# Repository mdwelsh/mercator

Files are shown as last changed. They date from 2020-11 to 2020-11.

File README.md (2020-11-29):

# Mercator

Mercator is a spherical persistence-of-vision display based on ESP32 and
DotStar LEDs. This repo contains the full source files, laser cut and 3D
printed parts designs, and custom PCB design.

For more details, please check out the article here:
https://mdwdotla.medium.com/mercator-an-esp32-based-spherical-persistence-of-vision-display-a4beff4f826e

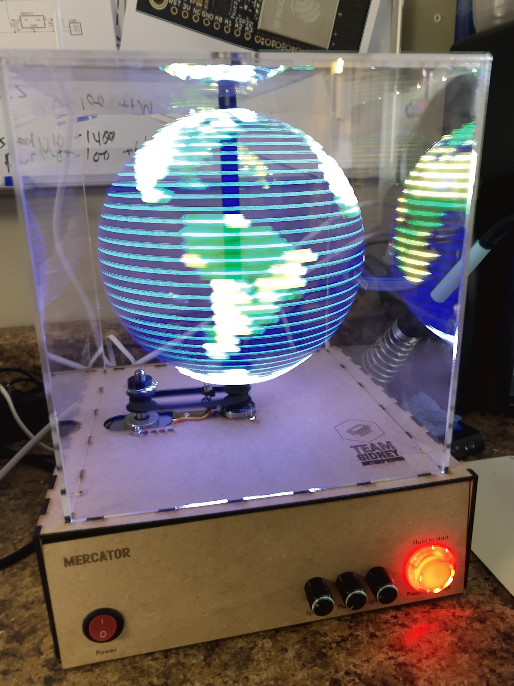
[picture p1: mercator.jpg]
Image of Mercator


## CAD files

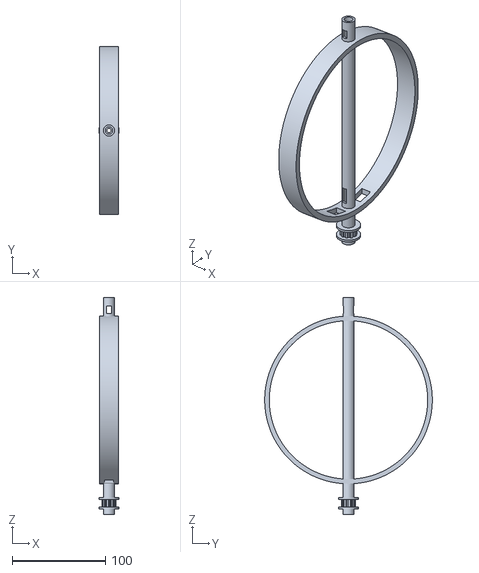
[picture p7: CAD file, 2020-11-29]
hardware/3dprint/Ring.stl
22.0 x 180.0 x 233.0

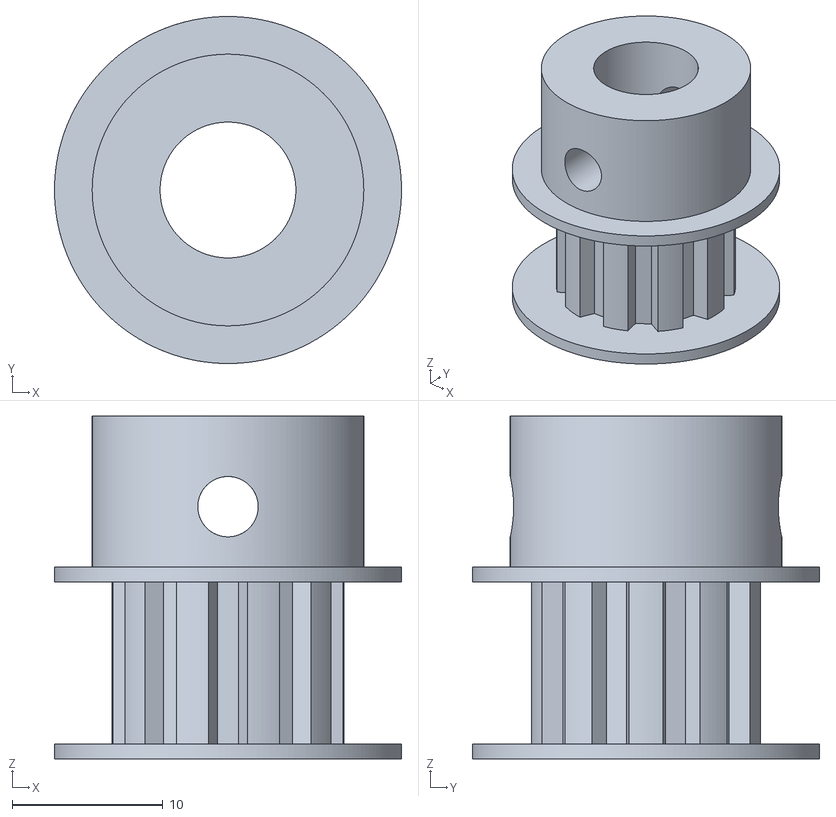
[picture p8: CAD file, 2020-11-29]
hardware/3dprint/XLPulley.stl
23.0 x 23.0 x 22.7

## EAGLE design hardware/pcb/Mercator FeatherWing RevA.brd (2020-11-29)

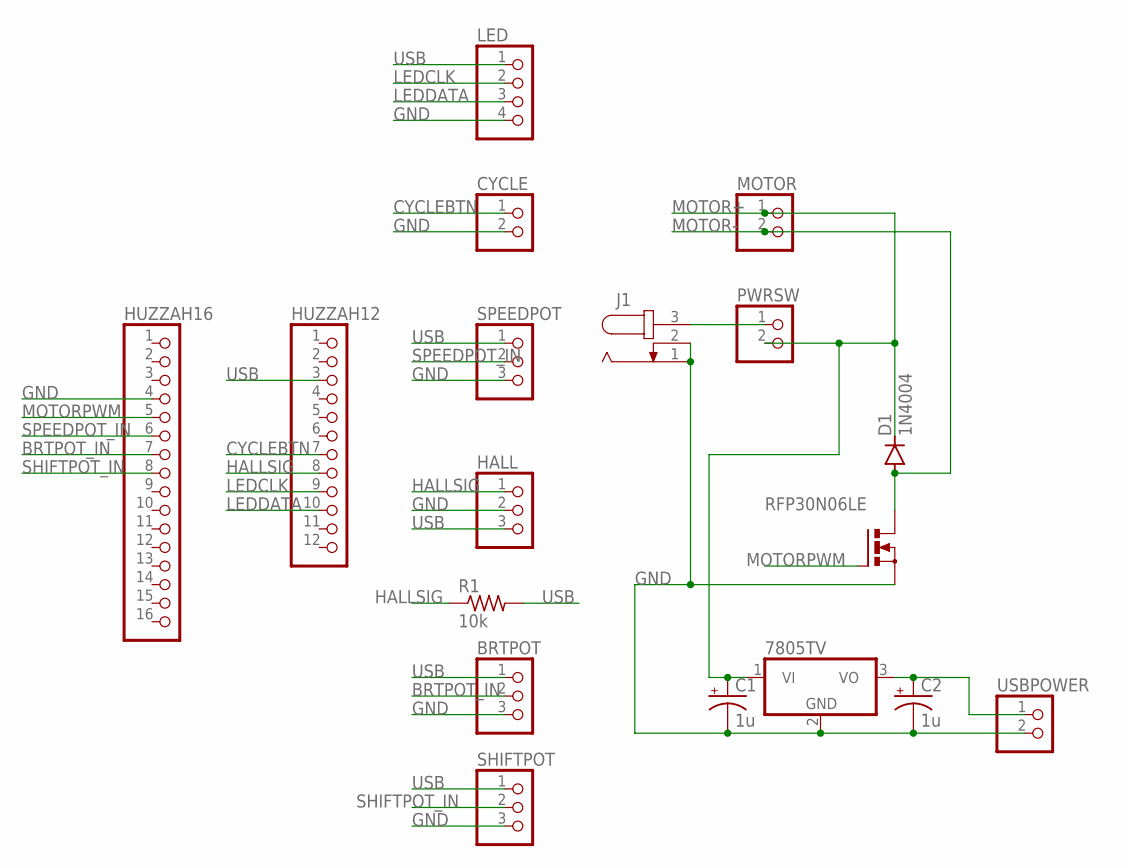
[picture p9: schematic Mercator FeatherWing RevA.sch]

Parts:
7805ABV: 7805TV; TO220V
BRTPOT: PINHD-1X3; 1X03
C1, C2: 1u; E2-5
CYCLE: PINHD-1X2; 1X02
D1: 1N4004; DO41-10
HALL: PINHD-1X3; 1X03
HUZZAH12: PINHD-1X12; 1X12
HUZZAH16: PINHD-1X16; 1X16
J1: JACK-PLUG0; SPC4077
LED: PINHD-1X4; 1X04
MOTOR: PINHD-1X2; 1X02
PWRSW: PINHD-1X2; 1X02
R1: 10k; 0207/10
RFP30N06LE: PMOSFET_NTO220BV; TO220BV
SHIFTPOT: PINHD-1X3; 1X03
SPEEDPOT: PINHD-1X3; 1X03
USBPOWER: PINHD-1X2; 1X02

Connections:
BRTPOT_IN: BRTPOT.2, HUZZAH16.7
CYCLEBTN: CYCLE.1, HUZZAH12.7
GND: 7805ABV.2 (GND), BRTPOT.3, C1.-, C2.-, CYCLE.2, HALL.2, HUZZAH16.4, J1.1, J1.2, LED.4, RFP30N06LE.S, SHIFTPOT.3, SPEEDPOT.3, USBPOWER.2
HALLSIG: HALL.1, HUZZAH12.8, R1.1
LEDCLK: HUZZAH12.9, LED.2
LEDDATA: HUZZAH12.10, LED.3
MOTOR+: 7805ABV.1 (VI), C1.+, D1.C, MOTOR.1, PWRSW.2
MOTOR-: D1.A, MOTOR.2, RFP30N06LE.D
MOTORPWM: HUZZAH16.5, RFP30N06LE.G
unnamed: J1.3, PWRSW.1
SHIFTPOT_IN: HUZZAH16.8, SHIFTPOT.2
SPEEDPOT_IN: HUZZAH16.6, SPEEDPOT.2
USB: BRTPOT.1, HALL.3, HUZZAH12.3, LED.1, R1.2, SHIFTPOT.1, SPEEDPOT.1
USB+: 7805ABV.3 (VO), C2.+, USBPOWER.1

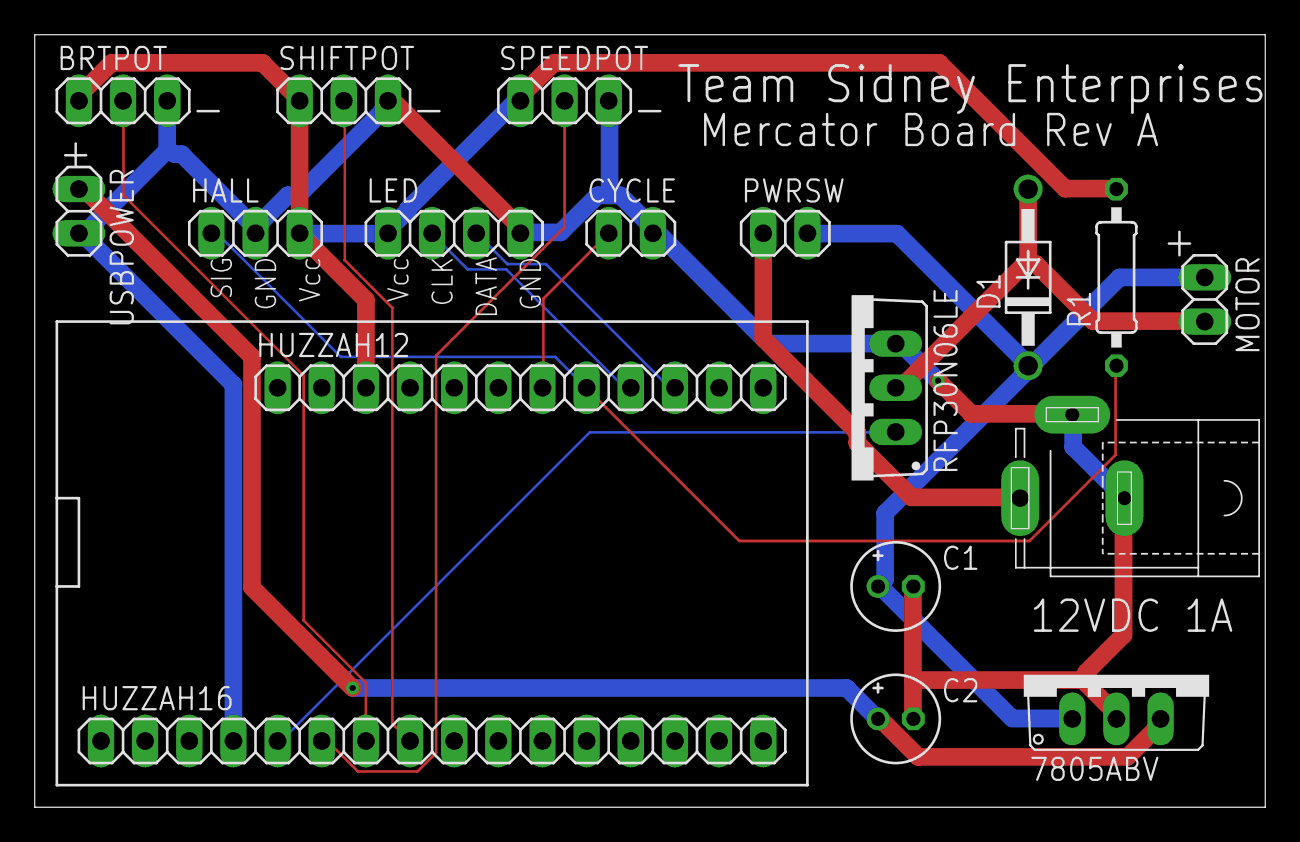
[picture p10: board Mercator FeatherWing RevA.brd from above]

Board: 2 copper layers, 70.8 x 44.4 mm, 18 parts (0 on the bottom side), 14 nets.

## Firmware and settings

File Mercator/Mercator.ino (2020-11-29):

// Mercator.ino
// Matt Welsh - mdw@mdw.la
// https://www.mdw.la/
//
//
// This is Arduino code for Mercator, a spherical persistence-of-vision display
// powered by an ESP32 dev board and Adafruit Dotstar LED strip. For more details,
// see: https://github.com/mdwelsh/mercator

#include <Adafruit_DotStar.h>
#include <SPI.h>

// Include each of the images. These are generated using genheader.py.
#include "images/earth.h"
#include "images/pacman.h"
#include "images/spaceinvaders.h"
#include "images/jackolantern.h"
#include "images/tselogo.h"
#include "images/octoml.h"
#include "images/octoml_name.h"
#include "images/tabbyslime.h"
#include "images/hollowknight.h"
#include "images/deathstar.h"

// Image data for Game of Life.
#define IMAGE_ROWS_life 36
#define IMAGE_COLUMNS_life 72
static uint8_t IMAGE_life[IMAGE_COLUMNS_life * IMAGE_ROWS_life * 3];

typedef struct _image_metadata {
  uint8_t* data;
  int columns;
  int rows;
} image_metadata;

#define MAKEIMAGE(_name, _columns, _rows) (image_metadata){ data: (uint8_t*)&_name[0], columns: _columns, rows: _rows, }

#define NUM_IMAGES 11
image_metadata images[NUM_IMAGES] = {
  MAKEIMAGE(IMAGE_earth, IMAGE_COLUMNS_earth, IMAGE_ROWS_earth),
  MAKEIMAGE(IMAGE_pacman, IMAGE_COLUMNS_pacman, IMAGE_ROWS_pacman),
  MAKEIMAGE(IMAGE_spaceinvaders, IMAGE_COLUMNS_spaceinvaders, IMAGE_ROWS_spaceinvaders),
  MAKEIMAGE(IMAGE_jackolantern, IMAGE_COLUMNS_jackolantern, IMAGE_ROWS_jackolantern),
  MAKEIMAGE(IMAGE_tselogo, IMAGE_COLUMNS_tselogo, IMAGE_ROWS_tselogo),
  MAKEIMAGE(IMAGE_octoml, IMAGE_COLUMNS_octoml, IMAGE_ROWS_octoml),
  MAKEIMAGE(IMAGE_octoml_name, IMAGE_COLUMNS_octoml_name, IMAGE_ROWS_octoml_name),
  MAKEIMAGE(IMAGE_tabby, IMAGE_COLUMNS_tabby, IMAGE_ROWS_tabby),
  MAKEIMAGE(IMAGE_hollowknight, IMAGE_COLUMNS_hollowknight, IMAGE_ROWS_hollowknight),
  MAKEIMAGE(IMAGE_deathstar, IMAGE_COLUMNS_deathstar, IMAGE_ROWS_deathstar),
  MAKEIMAGE(IMAGE_life, IMAGE_COLUMNS_life, IMAGE_ROWS_life),
};

#define LIFE_IMAGE_INDEX NUM_IMAGES-1
// Binary count data for each GOL cell.
static uint8_t life1[IMAGE_COLUMNS_life * IMAGE_ROWS_life];
static uint8_t life2[IMAGE_COLUMNS_life * IMAGE_ROWS_life];
uint8_t *cur_life = life1;

// Number of LEDs in the strip.
#define NUMPIXELS 72
// Data pin for the DotStar strip.
#define DATAPIN    14
// Clock pin for the DotStar strip.
#define CLOCKPIN   32
Adafruit_DotStar strip(NUMPIXELS, DATAPIN, CLOCKPIN, DOTSTAR_BGR);

// If defined, will flash red when Hall effect sensor triggers.
//#define HALLDEBUG
// Input pin for the Hall effect sensor.
#define HALLPIN  15
// Output pin for the motor PWM signal.
#define PWMPIN A0
// Input pin for the speed potentiometer.
#define SPEEDPOT A1
// Input pin for the brightness potentiometer.
#define BRTPOT A2
// Input pin for the phase potentiometer.
#define SHIFTPOT A3
// Input pin for the button potentiometer.
#define BUTTONPIN 33

// Configuration for PWM output.
#define LEDC_CHANNEL_0 0
#define LEDC_TIMER_13_BIT 13
#define LEDC_BASE_FREQ 10000

// Initial LED strip brightness value.
#define BRIGHTNESS 20
// Number of columns displayed in a single revolution.
#define NUM_COLUMNS 72

// Time in microsecoonds after which a failed Hall effect detection turns off the LEDs.
#define IDLE_TIME 1000000
// Alpha parameter for EWMA calculation of revolution time.
#define ALPHA 0.5
// If defined, only show pattern on the front LED strip (rather than on both front and back).
//#define FRONT_STRIP_ONLY
// If defined, flash red when the motor is spinning too fast to display all columns in one revolution.
#define WARN_IF_TOO_FAST
// Static offset for shifting pixel display in X and Y dimensions.
#define X_SHIFT 0
#define Y_SHIFT 0
// Y-offset in pixels for back strip versus front strip.
#define BACK_OFFSET 3
// Time in microseconds to trigger next longitudinal shift in the image.
#define ROTATE_INTERVAL 10000
// Time in microseconds to step Game of Life simulation.
#define LIFE_INTERVAL 200000

int started = 0;
int cur_hall = 0;
int cur_step = 0;
int cur_x_offset = 0;
uint32_t last_hall_time = 0;
uint32_t last_rotate_time = 0;
uint32_t last_life_time = 0;
uint32_t last_clock_time = 0;
uint32_t last_button_time = 0;
uint32_t cycle_time = 0;
uint32_t per_column_time = 0;
uint32_t next_column_time = 0;
uint32_t start_button_pressed = 0;

int cur_image_index = 0;
image_metadata *cur_image = &images[cur_image_index];

// Set all pixels to the given color.
void setAll(uint32_t color) {
  for (int i = 0; i < NUMPIXELS; i++) {
    strip.setPixelColor(i, color);
  }
  strip.show();
}

// Interpolate between color1 and color2. mix represents the amount of color2.
uint32_t interpolate(uint32_t color1, uint32_t color2, float mix) {
  uint32_t r1 = (color1 & 0xff0000) >> 16;
  uint32_t r2 = (color2 & 0xff0000) >> 16;
  uint32_t r3 = (uint32_t)(r1 * (1.0-mix)) + (uint32_t)(r2 * mix) << 16;

  uint32_t g1 = (color1 & 0x00ff00) >> 8;
  uint32_t g2 = (color2 & 0x00ff00) >> 8;
  uint32_t g3 = (uint32_t)(g1 * (1.0-mix)) + (uint32_t)(g2 * mix) << 8;

  uint32_t b1 = (color1 & 0x0000ff);
  uint32_t b2 = (color2 & 0x0000ff);
  uint32_t b3 = (uint32_t)(b1 * (1.0-mix)) + (uint32_t)(b2 * mix);

  return r3 | g3 | b3;
}

// Input a value 0 to 255 to get a color value.
// The colours are a transition r - g - b - back to r.
uint32_t color_wheel(byte WheelPos) {
  WheelPos = 255 - WheelPos;
  if(WheelPos < 85) {
    return strip.Color(255 - WheelPos * 3, 0, WheelPos * 3);
  }
  if(WheelPos < 170) {
    WheelPos -= 85;
    return strip.Color(0, WheelPos * 3, 255 - WheelPos * 3);
  }
  WheelPos -= 170;
  return strip.Color(WheelPos * 3, 255 - WheelPos * 3, 0);
}

// Arduino like analogWrite.value must be between 0 and valueMax.
void ledcAnalogWrite(uint8_t channel, uint32_t value, uint32_t valueMax = 255) {
  // calculate duty, 8191 from 2 ^ 13 - 1
  uint32_t duty = (8191 / valueMax) * min(value, valueMax);

  // write duty to LEDC
  ledcWrite(channel, duty);
}

// Get the pixel value for the Life image data at the provided (x, y) position as a uint8_t.
uint8_t getPixel(uint8_t *image, int x, int y) {
  int xi = x % IMAGE_COLUMNS_life;
  int yi = y % IMAGE_ROWS_life;
  int index = (yi * IMAGE_COLUMNS_life) + xi;
  return image[index];
}

// Set the pixel value for the Life image data at the provided (x, y) position.
void setPixel(uint8_t *image, int x, int y, uint8_t value) {
  int xi = x % IMAGE_COLUMNS_life;
  int yi = y % IMAGE_ROWS_life;
  int index = (yi * IMAGE_COLUMNS_life) + xi;
  image[index] = value;
}

// Value for newly-live cells.
#define LIVE 0xff

// Initialize Game of Life data.
void init_life() {
  for (int y = 0; y < IMAGE_ROWS_life; y++) {
    for (int x = 0; x < IMAGE_COLUMNS_life; x++) {
      if (random(0, 5) < 1) {
        setPixel(cur_life, x, y, LIVE);
      } else {
        setPixel(cur_life, x, y, 0);
      }
    }
  }
}

// Return the new value of the given Life pixel.
uint8_t life(uint8_t *image, int x, int y) {
  int neighborCount = 0;
  if (getPixel(image, x-1, y-1) > 0) neighborCount++;
  if (getPixel(image, x-1, y) > 0) neighborCount++;
  if (getPixel(image, x-1, y+1) > 0) neighborCount++;
  if (getPixel(image, x, y-1) > 0) neighborCount++;
  if (getPixel(image, x, y+1) > 0) neighborCount++;
  if (getPixel(image, x+1, y-1) > 0) neighborCount++;
  if (getPixel(image, x+1, y) > 0) neighborCount++;
  if (getPixel(image, x+1, y+1) > 0) neighborCount++;
  uint8_t self = getPixel(image, x, y);
  if (self > 0 && (neighborCount == 2 || neighborCount == 3)) {
    if (self == 1) return 1;
    else return self-1;  // Decay cells over time.
  }
  if (self == 0 && neighborCount == 3) return LIVE;
  return 0;
}

// Evolve the Game of Life data by one step.
void step_life() {
  uint8_t *from = cur_life;
  uint8_t *to = (cur_life == life1) ? life2 : life1;
  for (int y = 0; y < IMAGE_ROWS_life; y++) {
    for (int x = 0; x < IMAGE_COLUMNS_life; x++) {
      uint8_t val = life(from, x, y);
      setPixel(to, x, y, val);
      uint32_t color = val == 0 ? 0 : color_wheel(val);
      IMAGE_life[((y * IMAGE_COLUMNS_life) + x) * 3] = (color >> 16) & 0xff;
      IMAGE_life[(((y * IMAGE_COLUMNS_life) + x) * 3) + 1] = (color >> 8) & 0xff;
      IMAGE_life[(((y * IMAGE_COLUMNS_life) + x) * 3) + 2] = color & 0xff;
    }
  }
  // Swap from and to images.
  cur_life = to;
}

void setup() {
  Serial.begin(115200);
  Serial.println("Initializing...");
  
  pinMode(LED_BUILTIN, OUTPUT);
  pinMode(HALLPIN, INPUT_PULLUP);
  pinMode(PWMPIN, OUTPUT);
  pinMode(SPEEDPOT, INPUT);
  pinMode(SHIFTPOT, INPUT);
  pinMode(BRTPOT, INPUT);
  pinMode(BUTTONPIN, INPUT_PULLUP);
  ledcSetup(LEDC_CHANNEL_0, LEDC_BASE_FREQ, LEDC_TIMER_13_BIT);
  ledcAttachPin(PWMPIN, LEDC_CHANNEL_0);
  ledcAnalogWrite(LEDC_CHANNEL_0, 0);

  last_hall_time = micros();
  next_column_time = micros();

  strip.begin();
  strip.show();
  strip.setBrightness(BRIGHTNESS);
  setAll(0xff0000);
  delay(200);
  setAll(0x00ff00);
  delay(200);
  setAll(0x0000ff);
  delay(200);
}

uint32_t get_color(int x, int y) {
  if (x < 0 || x > cur_image->columns-1) return 0x0;
  if (y < 0 || y > cur_image->rows-1) return 0x0;
  int index = (y * cur_image->columns * 3) + (x * 3);
  uint8_t* p = (uint8_t*)&cur_image->data[index];
  uint32_t* pv = (uint32_t*)p;
  uint32_t pixel = (*pv) & 0xffffff;
  return pixel;
}

void doPaint(uint32_t cur_time) {
  if (cur_time < next_column_time) {
    return;
  }
  
  int x = (cur_step - X_SHIFT + cur_x_offset) % NUM_COLUMNS;
  int frontx = x;
  int backx = (x + (NUM_COLUMNS/2)) % NUM_COLUMNS;

  // Front strip.
  for (int i = 0; i < NUMPIXELS/2; i++) {
    int y = (NUMPIXELS/2) - i;   // Swap y-axis.
    strip.setPixelColor(i, get_color(frontx, y));
  }

  // Back strip.
  for (int i = NUMPIXELS/2; i < NUMPIXELS; i++) {
    int y = i - (NUMPIXELS/2) + BACK_OFFSET;
#ifdef FRONT_STRIP_ONLY
    strip.setPixelColor(i, 0x0);
#else
    strip.setPixelColor(i, get_color(backx, y));
#endif
  }

  strip.show();
  cur_step++;
  next_column_time = cur_time + per_column_time;
}

// White pulsing while waiting to start.
#define PULSE_LOW 0x0
#define PULSE_HIGH 0x404040
#define PULSE_STEP 0.0015
float cur_pulse = 0.0;
float pulse_step;
void pulse() {
  if (cur_pulse <= 0.0) {
    pulse_step = PULSE_STEP;
  } else if (cur_pulse >= 1.0) {
    pulse_step = -PULSE_STEP;
  }
  cur_pulse += pulse_step;
  setAll(interpolate(PULSE_LOW, PULSE_HIGH, cur_pulse));
}

void loop() {
  uint32_t cur_time = micros();

  int btn = digitalRead(BUTTONPIN);
  if (btn == LOW) {
    digitalWrite(LED_BUILTIN, HIGH);
  } else {
    digitalWrite(LED_BUILTIN, LOW);
  }

#define SAFE_START
#ifdef SAFE_START
  if (!started) {
    if (btn == HIGH) {
      start_button_pressed = 0;
    } else if (start_button_pressed == 0 && btn == LOW) {
      start_button_pressed = cur_time;
    } else if (start_button_pressed > 0 && cur_time - start_button_pressed > 1000000 && btn == LOW) {
      setAll(0x00ff00);
      delay(250);
      started = 1;
      return;
    }
    pulse();
    return;
  }
#endif  // SAFE_START
  
  int speedPotVal = analogRead(SPEEDPOT);
  ledcAnalogWrite(LEDC_CHANNEL_0, speedPotVal >> 5);
  
  int shiftPotVal = analogRead(SHIFTPOT);
  int brtPotVal = analogRead(BRTPOT);
  strip.setBrightness(brtPotVal >> 6);

  if (btn == HIGH) {
    start_button_pressed = 0;
  } else if (start_button_pressed == 0 && btn == LOW) {
    start_button_pressed = cur_time;
  } else if (start_button_pressed > 0 && cur_time - start_button_pressed > 250000 && btn == LOW) {
    cur_image_index++;
    cur_image_index %= NUM_IMAGES;
    cur_image = &images[cur_image_index];
    if (cur_image_index == LIFE_IMAGE_INDEX) {
      init_life();
    }
    start_button_pressed = 0;
  }

  int hall = digitalRead(HALLPIN);

  if (hall == LOW && cur_hall == 0) {
    if (cur_time - last_hall_time > 10000) {  // Debounce.
#ifdef HALLDEBUG
    setAll(0xff0000);
#endif      
      cur_hall = 1;

#ifdef WARN_IF_TOO_FAST
      if (cur_step < NUM_COLUMNS-2 && cur_image_index != LIFE_IMAGE_INDEX) {
        setAll(0xff0000);
      }
#endif
      cur_step = 0; // Reset cycle.
      cycle_time = (ALPHA * cycle_time) + ((1.0 - ALPHA) * (cur_time - last_hall_time));
      per_column_time = (cycle_time / NUM_COLUMNS);
      next_column_time = cur_time - per_column_time;
      last_hall_time = cur_time;

#ifdef ROTATE_INTERVAL
      if (cur_time - last_rotate_time > ROTATE_INTERVAL) {
        if (shiftPotVal > 2048) {
          cur_x_offset += (shiftPotVal - 2048) >> 8;
          cur_x_offset %= NUM_COLUMNS;
        } else if (shiftPotVal > 512) {
          cur_x_offset += NUM_COLUMNS - ((shiftPotVal - 512) >> 8);
          cur_x_offset %= NUM_COLUMNS;
        }
        last_rotate_time = cur_time;
      }
#else
      cur_x_offset = shiftPotVal >> 5;
#endif

      if (cur_image_index == LIFE_IMAGE_INDEX && cur_time - last_life_time > LIFE_INTERVAL) {
        step_life();
        last_life_time = cur_time;
      }
    }
  } else if (hall == HIGH && cur_hall == 1) {
    cur_hall = 0;
#ifdef HALLDEBUG
    setAll(0x0);
#endif
  }
#ifndef HALLDEBUG
  if (cur_time - last_hall_time < IDLE_TIME) {
    doPaint(cur_time);
  } else {
    setAll(0x0);
  }
#endif

}
